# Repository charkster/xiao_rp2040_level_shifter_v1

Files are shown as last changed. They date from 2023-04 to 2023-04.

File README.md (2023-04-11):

# xiao_rp2040_level_shifter_v1
Add-on PCB board for Seeed Studio Xiao RP2040, using NVT2010PW level shifter and on-board 1.2V and 1.8V LDO regulators. An external VREFA may be driven (no jumper) to a custom voltage 2.5V or below. The NVT2010PW level shifter allows VREFA voltages as low as 0.9V.

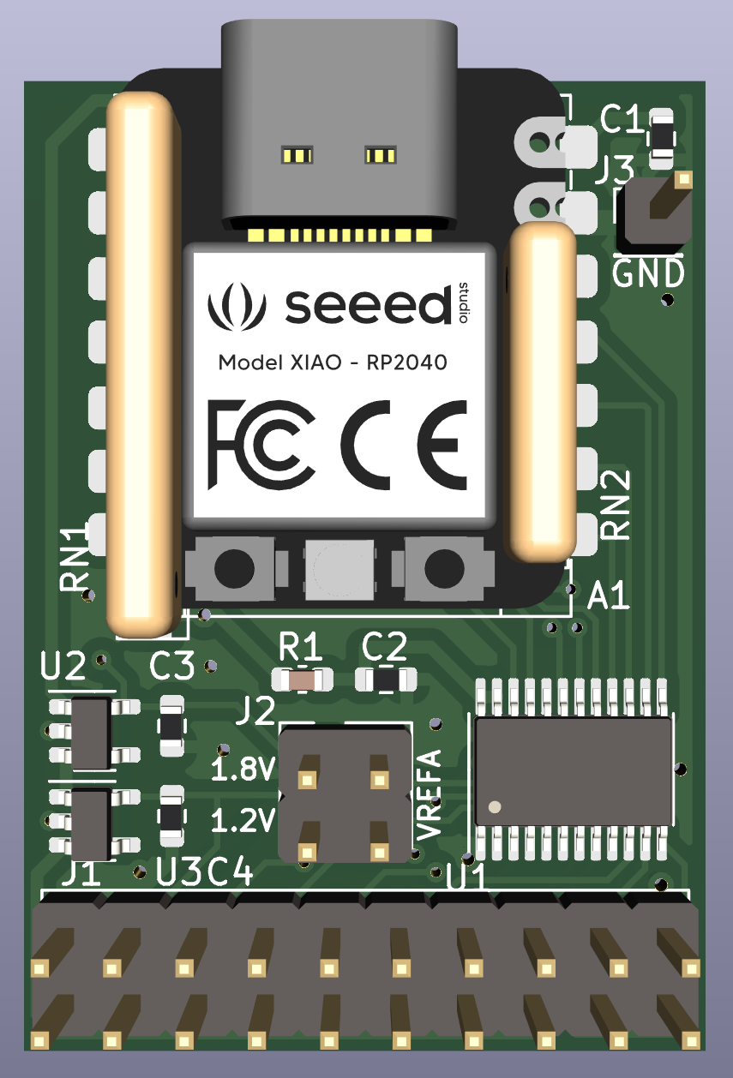
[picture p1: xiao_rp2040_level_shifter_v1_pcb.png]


Check-out my **PDF** [schematic](https://github.com/charkster/xiao_rp2040_level_shifter_v1/blob/main/xiao_rp2040_level_shifter_v1_schematic.pdf) !!

Check-out the CSV [**Bill of Materials**](https://github.com/charkster/xiao_rp2040_level_shifter_v1/blob/main/xiao_rp2040_level_shifter_v1_BOM.csv) !!

Pin 1 of J1 is bottom left (it is rotated 90 deg CCW).

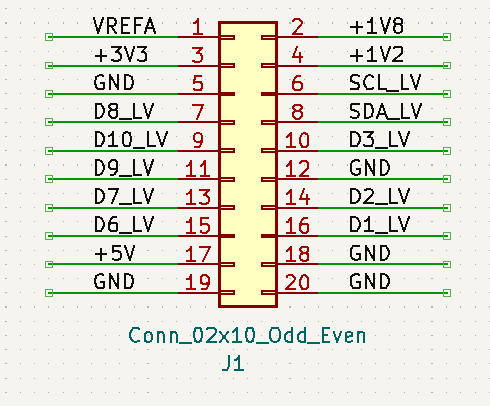
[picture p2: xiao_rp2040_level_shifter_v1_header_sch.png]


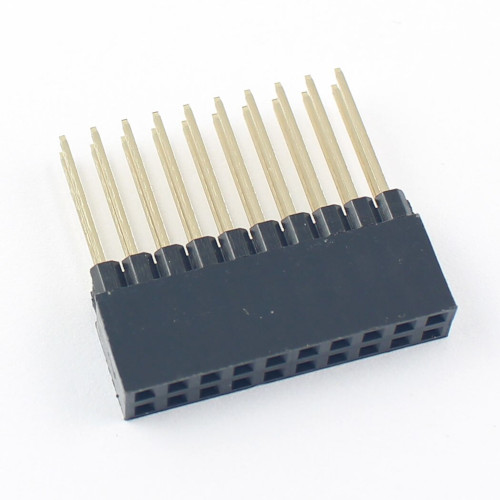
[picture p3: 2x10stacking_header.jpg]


2x10 2.54mm stacking headers can be found on [Aliexpress](https://www.aliexpress.us/item/2251832794527968.html?gatewayAdapt=glo2usa4itemAdapt&_randl_shipto=US)

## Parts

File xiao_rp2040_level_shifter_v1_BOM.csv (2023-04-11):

Source: | xiao_level_shifter_v1.kicad_sch
Date: | Mon 10 Apr 2023 09:02:22 PM MST
Tool: | Eeschema 6.0.2+dfsg-1
Generator: | /usr/share/kicad/plugins/bom_csv_grouped_by_value.py
Component Count: | 14
Individual Components:
Item | Qty | Reference(s) | Value | LibPart | Footprint | Datasheet
 |  | A1 | Adafruit_QT_PY | xiao_level_shifter_v1:Adafruit_QT_PY | xiao_level_shifter_v1:Adafruit_QT_PY_SMT | https://www.adafruit.com/product/4600
 |  | C1 | 10uF | Device:C | Resistor_SMD:R_0603_1608Metric | ~
 |  | C2 | 100pF | Device:C | Resistor_SMD:R_0603_1608Metric | ~
 |  | C3 | 10uF | Device:C | Resistor_SMD:R_0603_1608Metric | ~
 |  | C4 | 10uF | Device:C | Resistor_SMD:R_0603_1608Metric | ~
 |  | J1 | Conn_02x10_Odd_Even | Connector_Generic:Conn_02x10_Odd_Even | Connector_PinHeader_2.54mm:PinHeader_2x10_P2.54mm_Vertical | ~
 |  | J2 | Conn_02x02_Odd_Even | Connector_Generic:Conn_02x02_Odd_Even | Connector_PinHeader_2.54mm:PinHeader_2x02_P2.54mm_Vertical | ~
 |  | J3 | Conn_01x01 | Connector_Generic:Conn_01x01 | Connector_PinHeader_2.54mm:PinHeader_1x01_P2.54mm_Vertical | ~
 |  | R1 | 200k | Device:R | Capacitor_SMD:C_0603_1608Metric | ~
 |  | RN1 | 4608X-AP1-102LF | Device:R_Network07 | 4608X-AP1-102LF | https://www.mouser.com/datasheet/2/54/4600x-776645.pdf
 |  | RN2 | 4605X-101-100LF | Device:R_Network04 | xiao_level_shifter_v1:R_Array_SMT5 | https://www.mouser.com/datasheet/2/54/4600x-776645.pdf
 |  | U1 | NVT2010PW | xiao_level_shifter_v1:NVT2010PW | Package_SO:TSSOP-24_4.4x7.8mm_P0.65mm | https://www.nxp.com/docs/en/data-sheet/NVT2008_NVT2010.pdf
 |  | U2 | AP2112K-1.8 | Regulator_Linear:AP2112K-1.8 | Package_TO_SOT_SMD:SOT-23-5 | https://www.diodes.com/assets/Datasheets/AP2112.pdf
 |  | U3 | AP2112K-1.2 | Regulator_Linear:AP2112K-1.2 | Package_TO_SOT_SMD:SOT-23-5 | https://www.diodes.com/assets/Datasheets/AP2112.pdf
Collated Components:
Item | Qty | Reference(s) | Value | LibPart | Footprint | Datasheet
1 | 1 | A1 | Adafruit_QT_PY | xiao_level_shifter_v1:Adafruit_QT_PY | xiao_level_shifter_v1:Adafruit_QT_PY_SMT | https://www.adafruit.com/product/4600
2 | 3 | C1, C3, C4 | 10uF | Device:C | Resistor_SMD:R_0603_1608Metric | ~
3 | 1 | C2 | 100pF | Device:C | Resistor_SMD:R_0603_1608Metric | ~
4 | 1 | J1 | Conn_02x10_Odd_Even | Connector_Generic:Conn_02x10_Odd_Even | Connector_PinHeader_2.54mm:PinHeader_2x10_P2.54mm_Vertical | ~
5 | 1 | J2 | Conn_02x02_Odd_Even | Connector_Generic:Conn_02x02_Odd_Even | Connector_PinHeader_2.54mm:PinHeader_2x02_P2.54mm_Vertical | ~
6 | 1 | J3 | Conn_01x01 | Connector_Generic:Conn_01x01 | Connector_PinHeader_2.54mm:PinHeader_1x01_P2.54mm_Vertical | ~
7 | 1 | R1 | 200k | Device:R | Capacitor_SMD:C_0603_1608Metric | ~
8 | 1 | RN1 | 4608X-AP1-102LF | Device:R_Network07 | 4608X-AP1-102LF | https://www.mouser.com/datasheet/2/54/4600x-776645.pdf
9 | 1 | RN2 | 4605X-101-100LF | Device:R_Network04 | xiao_level_shifter_v1:R_Array_SMT5 | https://www.mouser.com/datasheet/2/54/4600x-776645.pdf
10 | 1 | U1 | NVT2010PW | xiao_level_shifter_v1:NVT2010PW | Package_SO:TSSOP-24_4.4x7.8mm_P0.65mm | https://www.nxp.com/docs/en/data-sheet/NVT2008_NVT2010.pdf
11 | 1 | U2 | AP2112K-1.8 | Regulator_Linear:AP2112K-1.8 | Package_TO_SOT_SMD:SOT-23-5 | https://www.diodes.com/assets/Datasheets/AP2112.pdf
12 | 1 | U3 | AP2112K-1.2 | Regulator_Linear:AP2112K-1.2 | Package_TO_SOT_SMD:SOT-23-5 | https://www.diodes.com/assets/Datasheets/AP2112.pdf

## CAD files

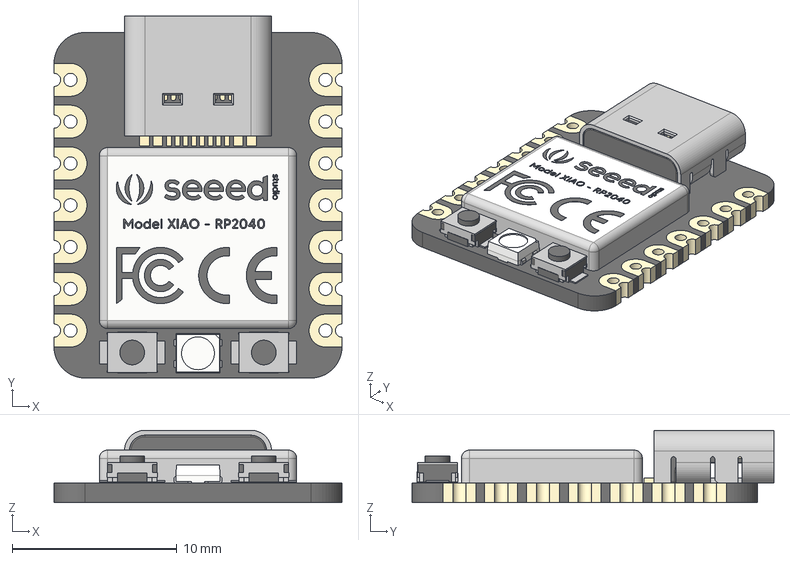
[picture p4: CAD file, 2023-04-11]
Seeed Studio XIAO RP2040 v26.step
17.5 x 22.0 x 4.40 mm
type-c v2
smd_button v3
DOUT
DIN
VSS
VDD
smd_button v3(Mirror)

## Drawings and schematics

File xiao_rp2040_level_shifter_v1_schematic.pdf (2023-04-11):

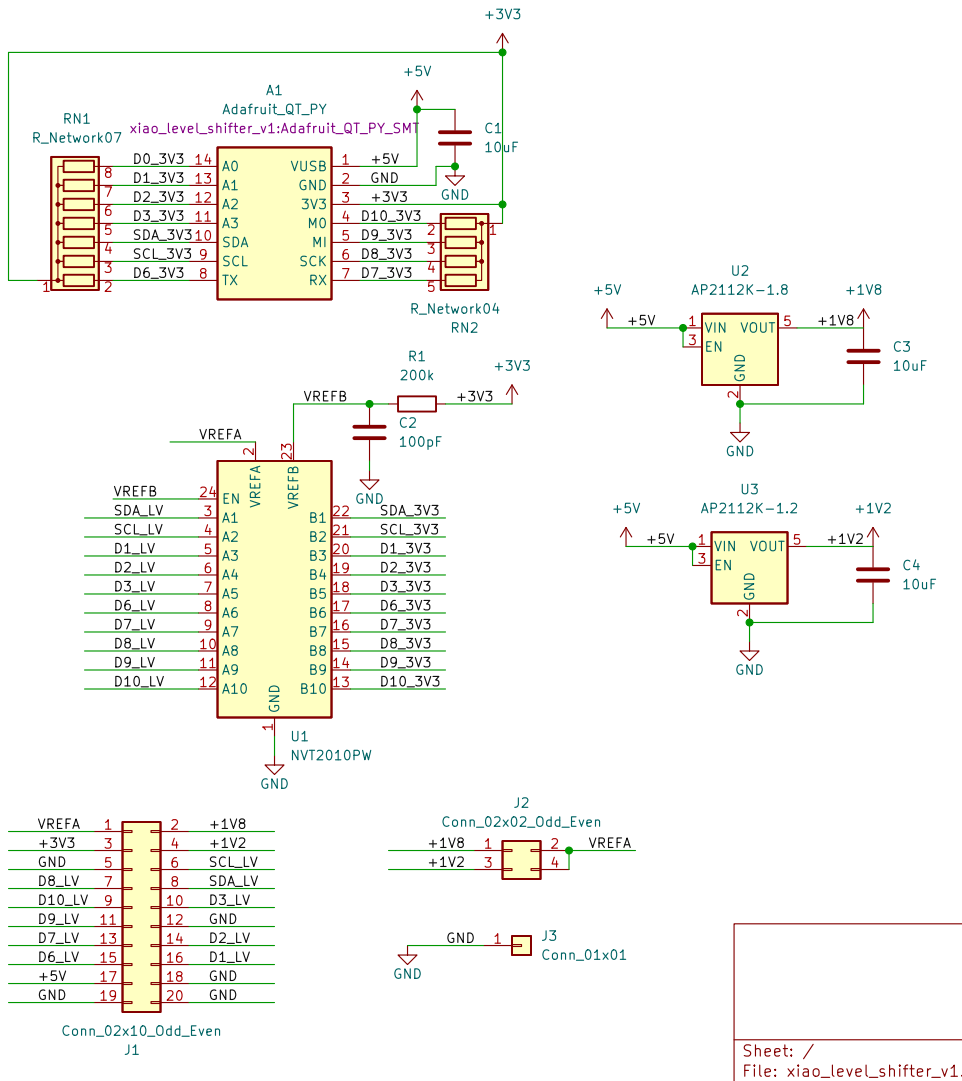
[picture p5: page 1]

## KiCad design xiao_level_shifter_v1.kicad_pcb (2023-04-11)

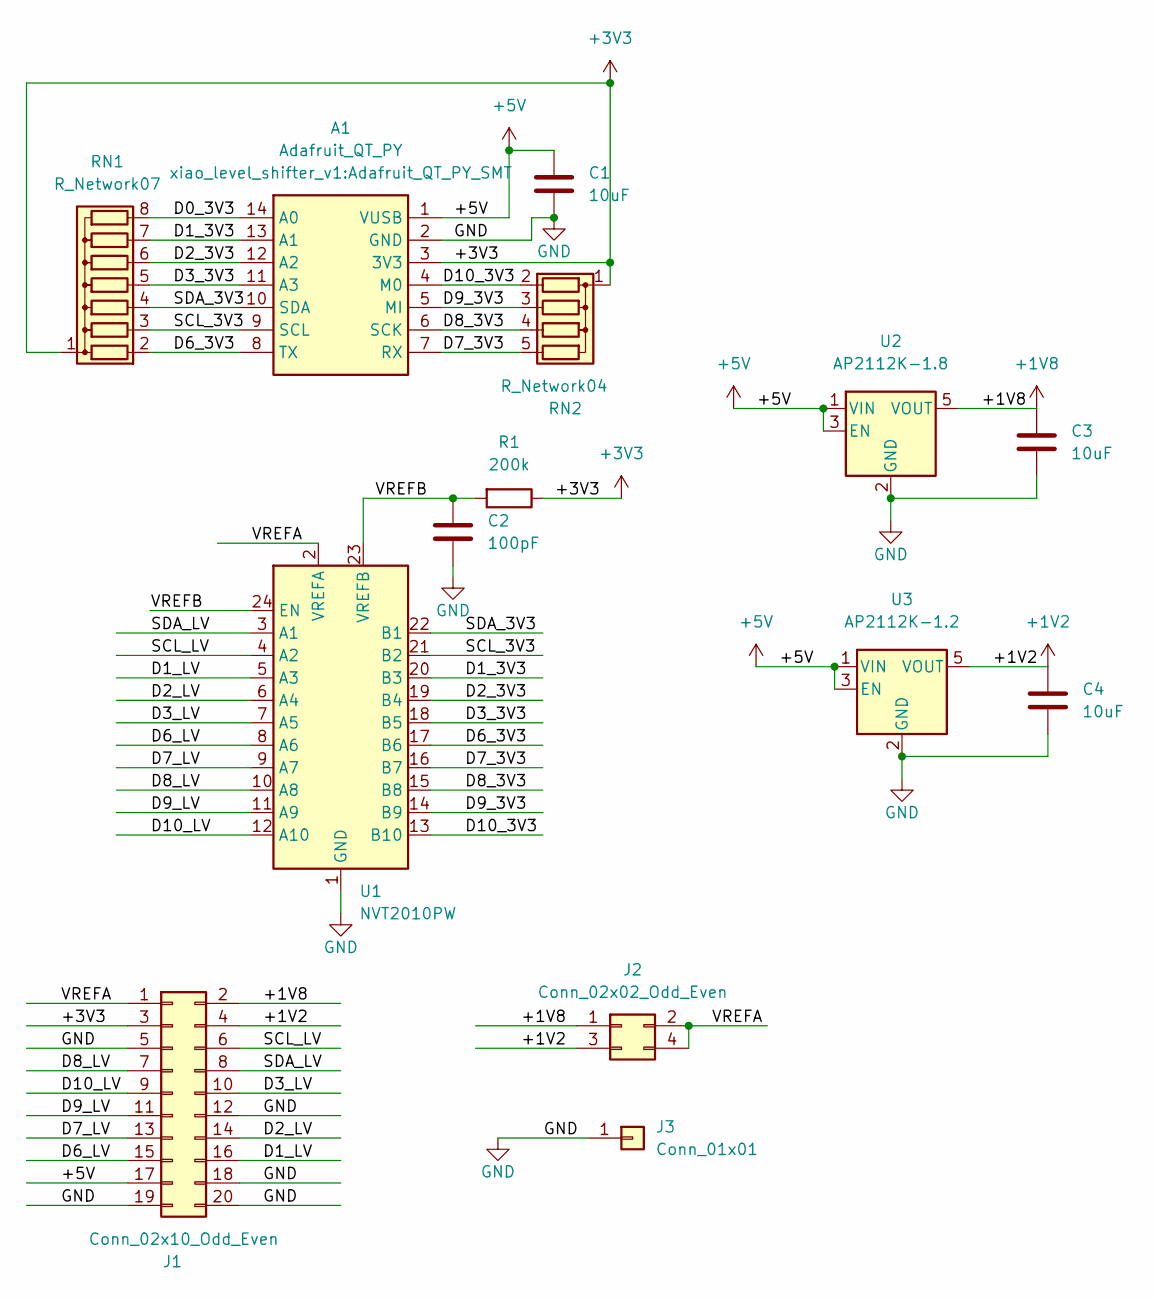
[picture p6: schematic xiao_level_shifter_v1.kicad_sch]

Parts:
A1: Adafruit_QT_PY; Adafruit_QT_PY_SMT
C1, C3, C4: 10uF; R_0603_1608Metric
C2: 100pF; R_0603_1608Metric
J1: Conn_02x10_Odd_Even; PinHeader_2x10_P2.54mm_Vertical
J2: Conn_02x02_Odd_Even; PinHeader_2x02_P2.54mm_Vertical
J3: Conn_01x01; PinHeader_1x01_P2.54mm_Vertical
R1: 200k; C_0603_1608Metric
RN1: R_Network07; R_Array_SMT8
RN2: R_Network04; R_Array_SMT5
U1: NVT2010PW; TSSOP-24_4.4x7.8mm_P0.65mm
U2: AP2112K-1.8; SOT-23-5
U3: AP2112K-1.2; SOT-23-5

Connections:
+1V2: C4.1, J1.4, J2.3, U3.5 (VOUT)
+1V8: C3.1, J1.2, J2.1, U2.5 (VOUT)
+3V3: A1.3 (3V3), J1.3, R1.1, RN1.1 (common), RN2.1 (common)
+5V: A1.1 (VUSB), C1.1, J1.17, U2.1 (VIN), U2.3 (EN), U3.1 (VIN), U3.3 (EN)
/D0_3V3: A1.14 (A0), RN1.8 (R7)
/D1_3V3: A1.13 (A1), RN1.7 (R6), U1.20 (B3)
/D1_LV: J1.16, U1.5 (A3)
/D2_3V3: A1.12 (A2), RN1.6 (R5), U1.19 (B4)
/D2_LV: J1.14, U1.6 (A4)
/D3_3V3: A1.11 (A3), RN1.5 (R4), U1.18 (B5)
/D3_LV: J1.10, U1.7 (A5)
/D6_3V3: A1.8 (TX), RN1.2 (R1), U1.17 (B6)
/D6_LV: J1.15, U1.8 (A6)
/D7_3V3: A1.7 (RX), RN2.5 (R4), U1.16 (B7)
/D7_LV: J1.13, U1.9 (A7)
/D8_3V3: A1.6 (SCK), RN2.4 (R3), U1.15 (B8)
/D8_LV: J1.7, U1.10 (A8)
/D9_3V3: A1.5 (MI), RN2.3 (R2), U1.14 (B9)
/D9_LV: J1.11, U1.11 (A9)
/D10_3V3: A1.4 (M0), RN2.2 (R1), U1.13 (B10)
/D10_LV: J1.9, U1.12 (A10)
/SCL_3V3: A1.9 (SCL), RN1.3 (R2), U1.21 (B2)
/SCL_LV: J1.6, U1.4 (A2)
/SDA_3V3: A1.10 (SDA), RN1.4 (R3), U1.22 (B1)
/SDA_LV: J1.8, U1.3 (A1)
/VREFA: J1.1, J2.2, J2.4, U1.2 (VREFA)
/VREFB: C2.1, R1.2, U1.23 (VREFB), U1.24 (EN)
GND: A1.2 (GND), C1.2, C2.2, C3.2, C4.2, J1.5, J1.12, J1.18, J1.19, J1.20, J3.1, U1.1 (GND), U2.2 (GND), U3.2 (GND)

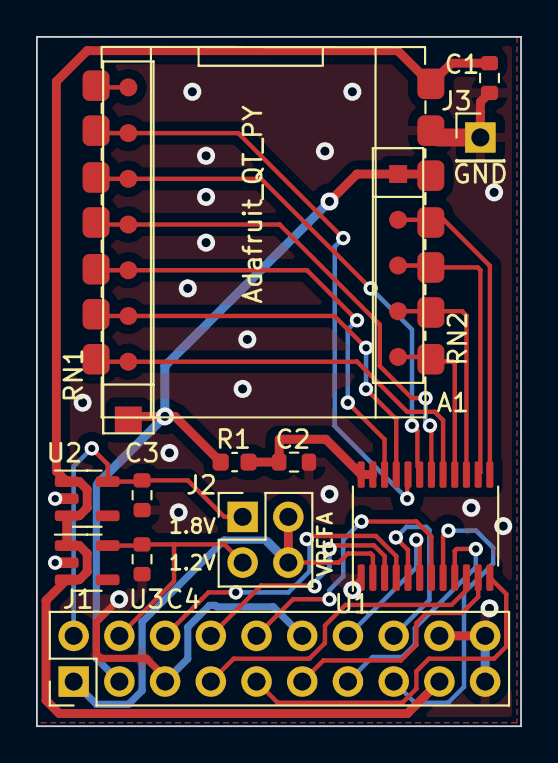
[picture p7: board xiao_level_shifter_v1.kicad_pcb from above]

Board: 2 copper layers, 26.9 x 38.3 mm, 14 parts (0 on the bottom side), 28 nets.
